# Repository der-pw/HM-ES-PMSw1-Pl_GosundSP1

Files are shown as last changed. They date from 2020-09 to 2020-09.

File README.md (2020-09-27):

# HM-ES-PMSw1-Pl_GosundSP1 PCB Version 2         

Umbau [Gosund SP1 bzw. BliTZWOLF SHP2](https://www.blitzwolf.com/Wifi-Smart-Socket-EU-p-244.html) zu HM-ES-PMSw1-Pl_SP1

In dieser Version 2 habe ich das Platinenlayout von [stan23](https://github.com/stan23) geändert.
Die SMD-Bauteile wurden auf Größe 0805 geändert und nur auf einer Seite arangiert, sodass einzig das Radio auf der Rückseite verbleibt und somit der Pinheader nicht mehr benötigt wird.

Weiterhin liegt das Original-Projekt hier: https://github.com/stan23/HM-ES-PMSw1-Pl_GosundSP1

Dies basiert auf der hervorragenden Arbeit von [pa-pa](https://github.com/pa-pa/AskSinPP) und [Jérôme](https://github.com/jp112sdl/Beispiel_AskSinPP).

*Achtung*: es kann verschiedene Versionen der Gosund/Blitzwolf-Stecker geben. Diese Platine passt bei folgender Version:
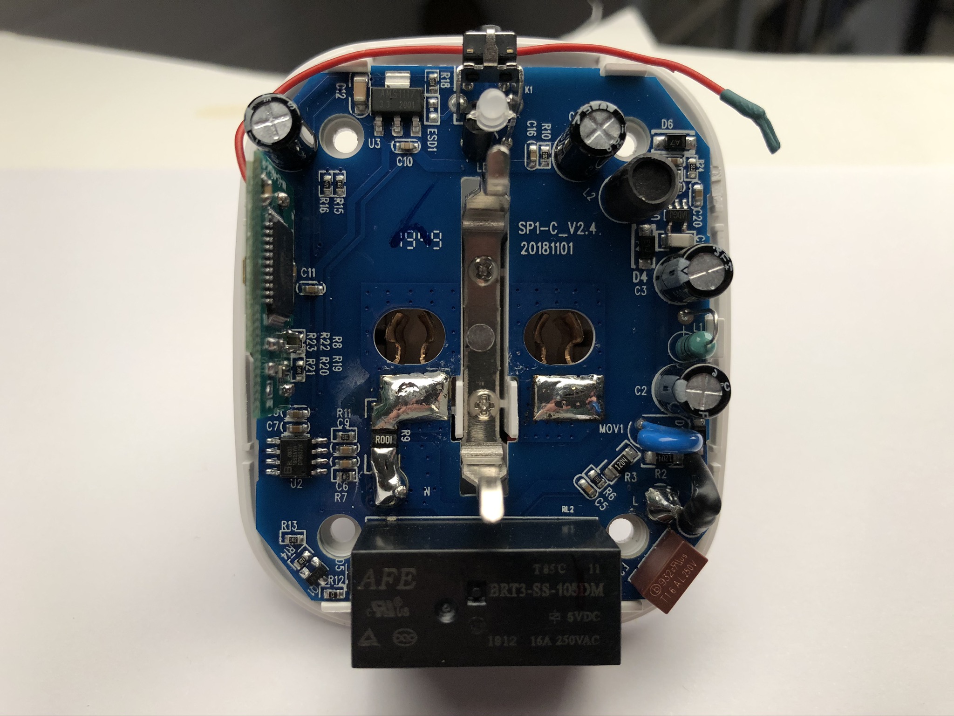
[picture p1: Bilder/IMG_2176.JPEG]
GosundSP1


## Teileliste
Bauteil                  | Bestellnummer   | Anzahl | Kommentar
------------------------ | --------------- | ------ | ---------
C1                       | X5R-G0805 10/6  |   1    | -
C2 .. C6                 | X7R-G0805 100N  |   5    | -
R1                       | RND 0805 1 10K  |   1    | -
R2                       | RND 0805 1 1,0M |   1    | -
U1                       | ATMEGA 644PA-AU |   1    | -
Y1                       | CSTCE 8,00      |   1    | ist EOL, aber über Ali noch zu beziehen

## Vergleich:

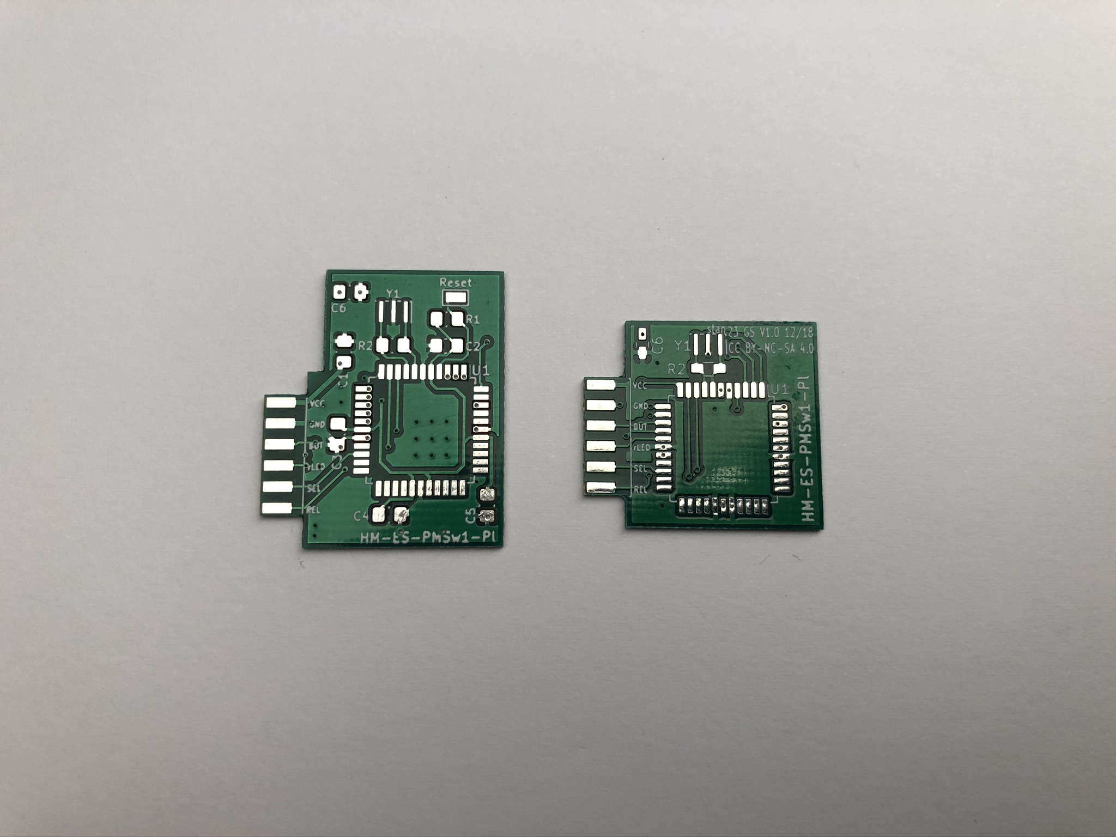
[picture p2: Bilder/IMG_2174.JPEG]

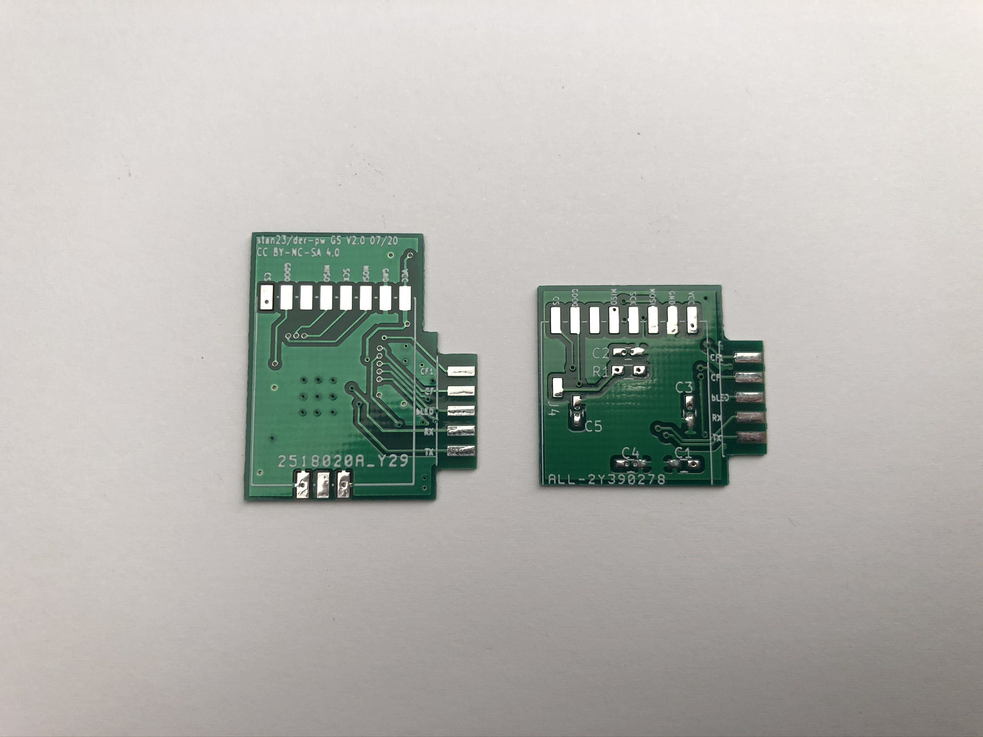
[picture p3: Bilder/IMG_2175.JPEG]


## Eingebaut

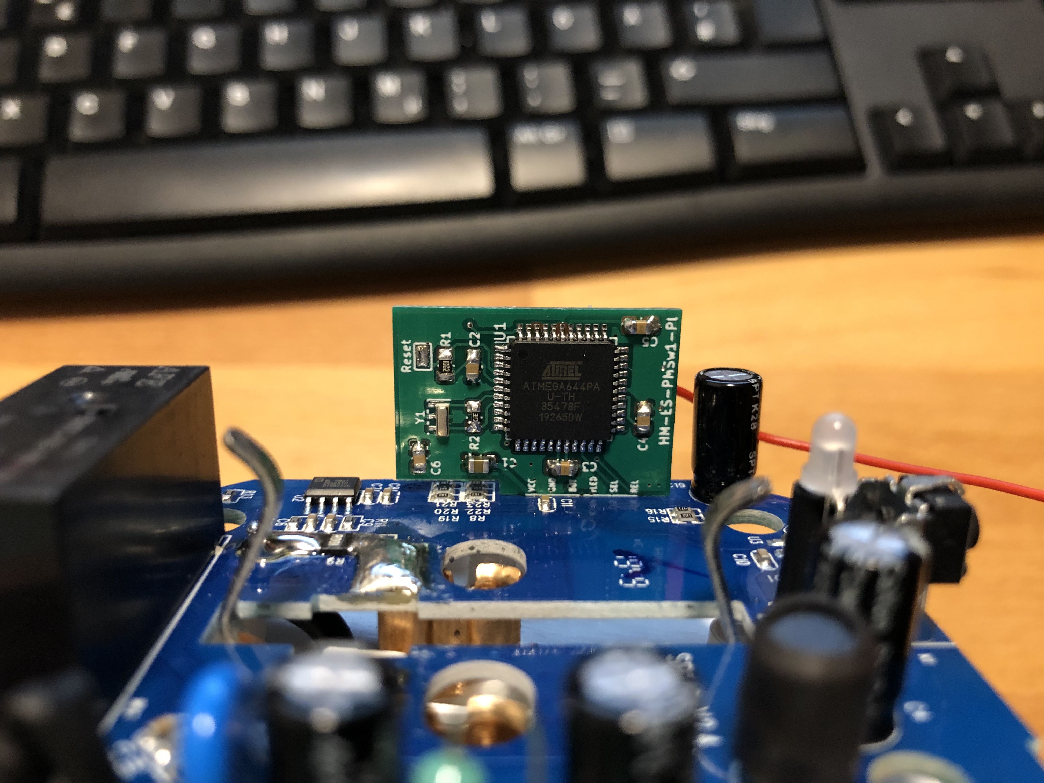
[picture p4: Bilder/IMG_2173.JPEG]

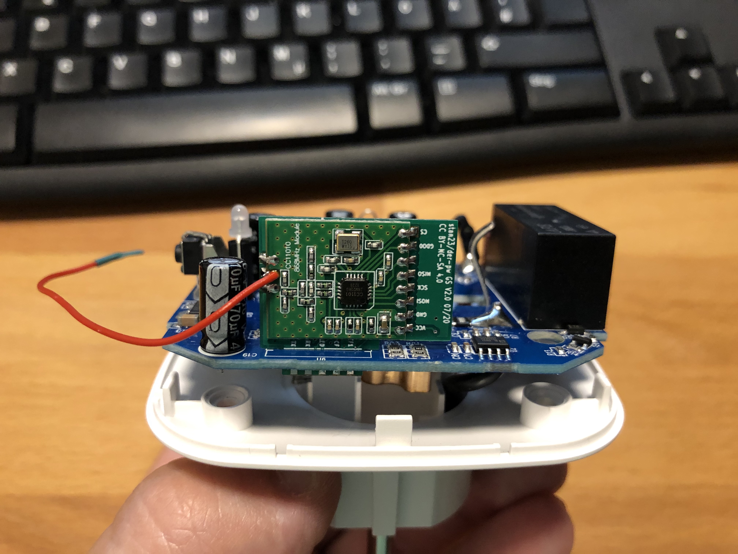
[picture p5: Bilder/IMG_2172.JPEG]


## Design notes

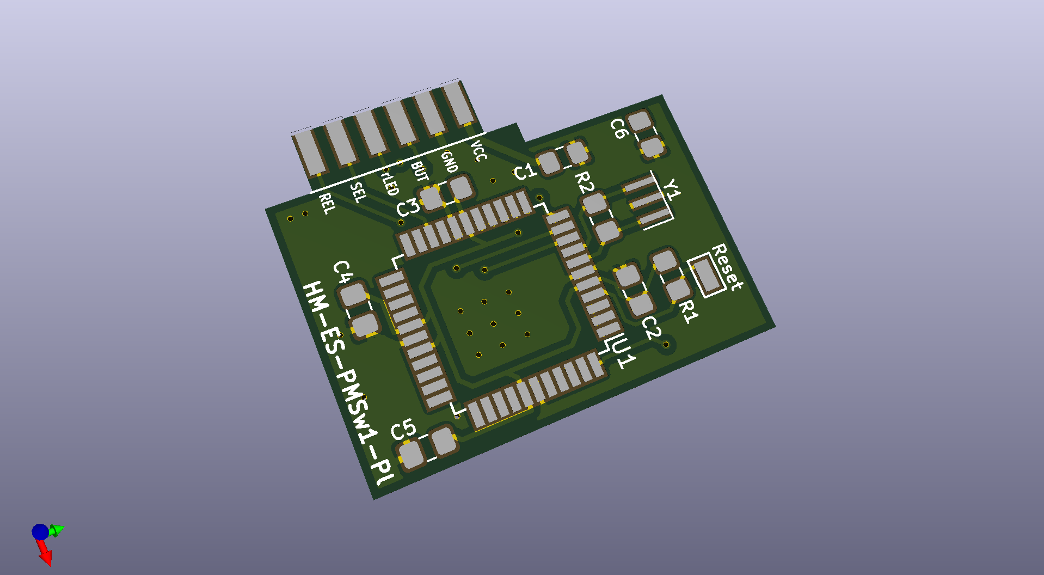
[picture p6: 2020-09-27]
Bilder/HM-ES-PMSw1-Pl_GosundSP1_top.png

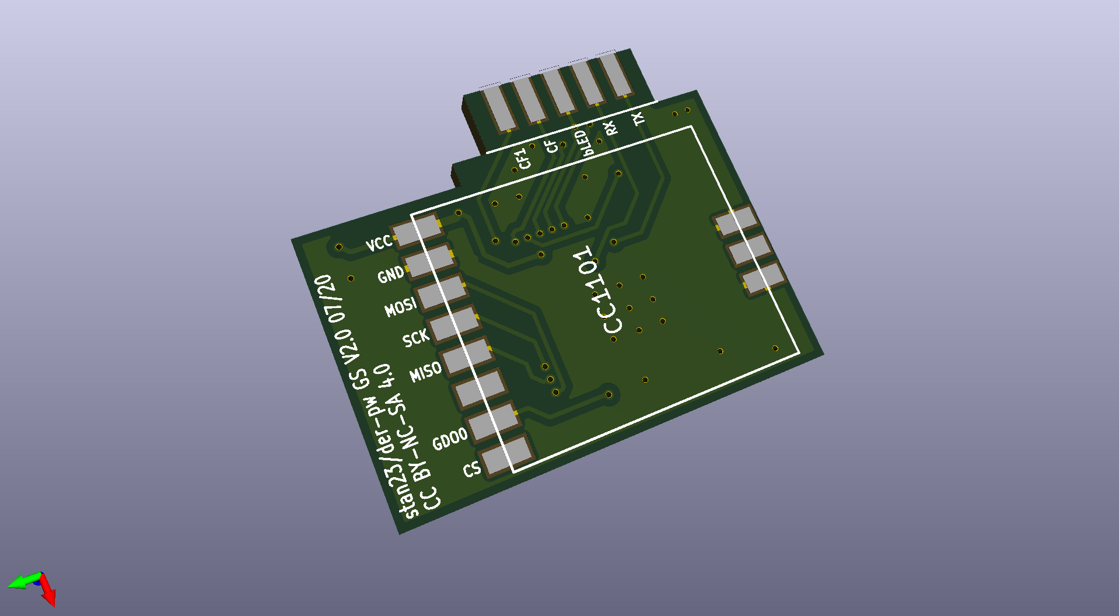
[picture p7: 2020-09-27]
Bilder/HM-ES-PMSw1-Pl_GosundSP1_bottom.png

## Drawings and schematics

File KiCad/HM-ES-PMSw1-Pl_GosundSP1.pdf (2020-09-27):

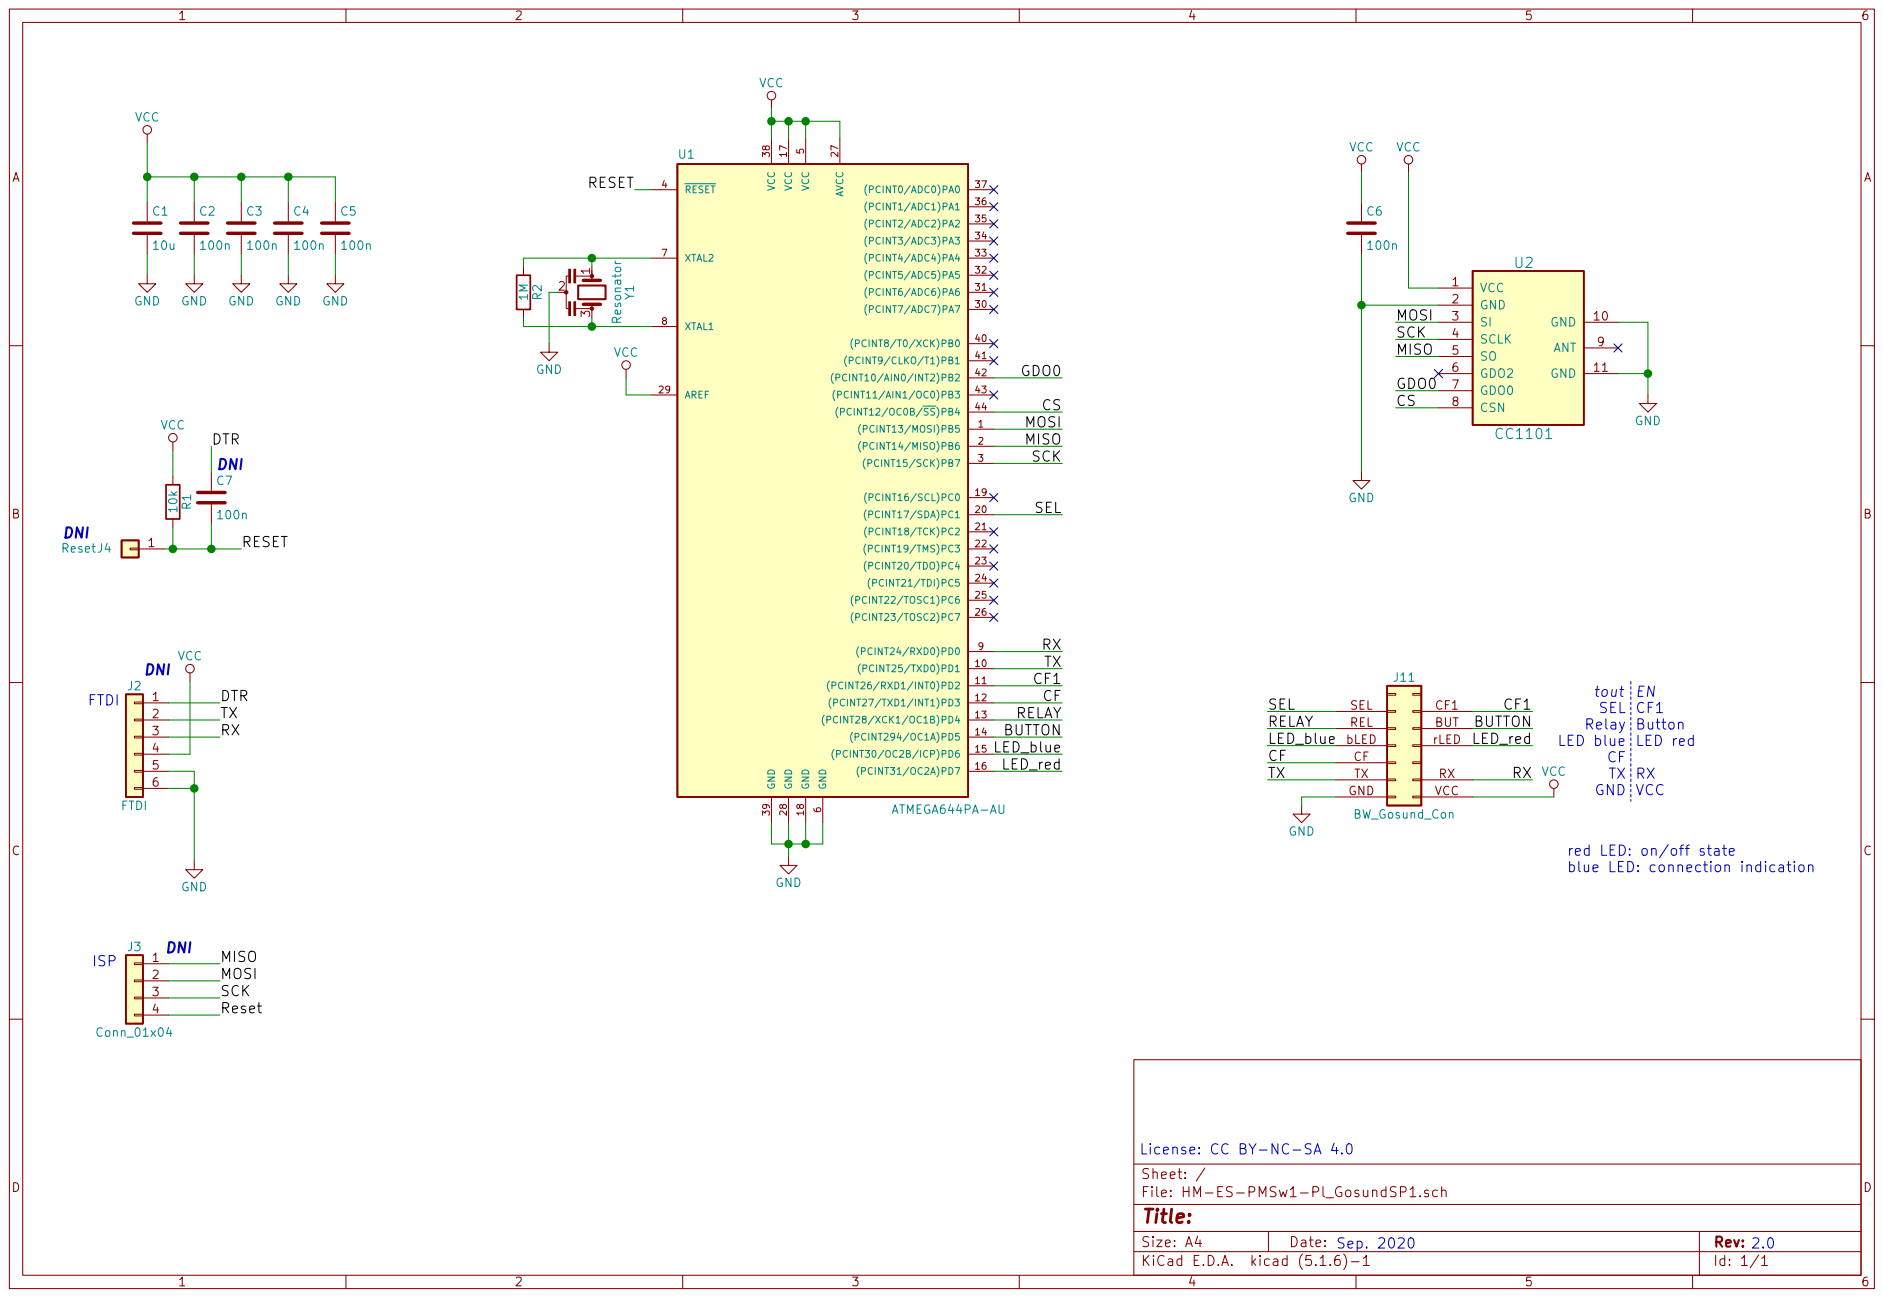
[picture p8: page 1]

3 Y1 Resonator GND GND GND

blue LED: connection indication

License: CC BY-NC-SA 4.0
File: HM-ES-PMSw1-Pl_GosundSP1.sch Sheet: /
Id: 1/1 Title:

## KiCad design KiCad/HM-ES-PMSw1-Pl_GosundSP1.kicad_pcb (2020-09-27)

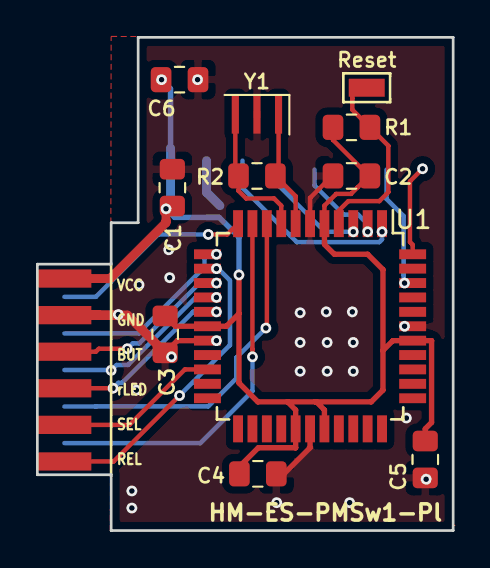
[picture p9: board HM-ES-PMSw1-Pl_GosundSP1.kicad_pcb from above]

Board: 2 copper layers, 23.1 x 27.4 mm, 13 parts (1 on the bottom side), 19 nets.

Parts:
C1: 10u; C_0805_2012Metric_Pad1.15x1.40mm_HandSolder
C2, C3, C4, C5, C6: 100n; C_0805_2012Metric_Pad1.15x1.40mm_HandSolder
J4: Reset; Testpad
J11: BW_Gosund_Con; Gosund_SP1-C_V2.3
R1: 10k; R_0805_2012Metric_Pad1.15x1.40mm_HandSolder
R2: 1M; R_0805_2012Metric_Pad1.15x1.40mm_HandSolder
U1: ATMEGA644PA-AU; TQFP-44_10x10mm_Pitch0.8mm
U2: CC1101; CC1101_Module
Y1: Resonator; Resonator_SMD_muRata_TPSKA-3pin_7.9x3.8mm_HandSoldering

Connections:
/BUTTON: J11.BUT, U1.14
/CF: J11.CF, U1.12
/CF1: J11.CF1, U1.11
/CS: U1.44, U2.8
/GDO0: U1.42, U2.7
/LED_blue: J11.bLED, U1.15
/LED_red: J11.rLED, U1.16
/MISO: U1.2, U2.5
/MOSI: U1.1, U2.3
/RELAY: J11.REL, U1.13
/RESET: J4.1, R1.2, U1.4
/RX: J11.RX, U1.9
/SCK: U1.3, U2.4
/SEL: J11.SEL, U1.20
/TX: J11.TX, U1.10
GND: C1.2, C2.2, C3.2, C4.2, C5.2, C6.2, J11.GND, U1.6, U1.18, U1.28, U1.39, U2.2, U2.10, U2.11, Y1.2
unnamed: R2.1, U1.7, Y1.1
unnamed: R2.2, U1.8, Y1.3
VCC: C1.1, C2.1, C3.1, C4.1, C5.1, C6.1, J11.VCC, R1.1, U1.5, U1.17, U1.27, U1.29, U1.38, U2.1
